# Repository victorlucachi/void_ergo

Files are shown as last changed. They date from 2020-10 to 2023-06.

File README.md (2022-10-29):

# VOID Ergo S
*A handwired split keyboard, running QMK firmware*

VOID Ergo S

|  |  |  |
|---|---|---|

###### More renders [here](https://imgur.com/a/ki1BZij)

The VOID Ergo S is a 3d printed, handwired, split keyboard with a layout similar to the Iris/Corne/Kyria, running QMK Firmware on Pro Micro controllers. Connection between the two halves of the keyboard is made with an aux cable via serial.

I suggest printing the case using a 0.4 mm nozzle, supports are not needed but recommended for the bottom cases as the ports will print with less imperfections.

The brass inserts can be fixed in the bottom case by heating them and applying pressure with a soldering iron set to about 200-220C.

*VOID Ergo S with V1 of the VOID Ergo under it*

VOID Ergo Fat

# Handwiring guide

I've also put together a pretty visual handwiring guide for the VOID9, that you can browse over [here](https://victorlucachi.ro/journal/void9-wiring-guide/).

|  	|  	|  	|
|---|---|---|

# Bill of Materials

* 46 diodes (tme.eu [link](https://www.tme.eu/ro/en/details/1n4148-dio/tht-universal-diodes/diotec-semiconductor/1n4148/)/aliexpress [link](https://www.aliexpress.com/item/32729204179.html))
* 44/46 cherry mx style switches
* 24 AWG (0.2 mm2) wire
* 2 x Pro Micro (aliexpress [link](https://www.aliexpress.com/item/32902569443.html))
* 2 x EC11 Rotary Encoder (optional/aliexpress [link](https://www.aliexpress.com/item/32872039030.html) mounted to the plate using [this adapter](https://www.thingiverse.com/thing:3770166))
* 10 x M2x12 allen head screws (aliexpress [link](https://www.aliexpress.com/item/32966941844.html), 14mm overall length, 4mm diameter head)
* 10 x M2 brass inserts (aliexpress [link](https://www.aliexpress.com/item/4000585933306.html), 3.5mm outer diameter)
* 2 x PJ320A 3.5mm female audio connectors (aliexpress [link](https://www.aliexpress.com/item/32368285821.html))
* 1 x 6x6x6 push button (optional (used to reset master)/aliexpress [link](https://www.aliexpress.com/item/32960657626.html))
* hot glue for securing the Pro Micros to the bottom case (optional, but recommended) the audio connectors and the reset push button.

# Pin assignment

    ROW0    ROW1    ROW2    ROW3
    B1      B3      B2      B6

    COL0    COL1    COL2    COL3    COL4    COL5
    D4      C6      D7      E6      B4      B5

    Encoder Pad A Left      Encoder Pad B Left
    F5                      F6

    Encoder Pad A Right     Encoder Pad B Right
    F6                      F5

    Serial Pin
    D1

*Matrix layout*

VOID Ergo S matrix layout

# QMK Vial Fork

A QMK Vial fork can be found [here](https://github.com/victorlucachi/vial-qmk/tree/dev_void/keyboards/handwired/void_ergo).

Most features are disabled in order for the firmware to fit on the atmega32u4 present on the Pro Micro controllers, but if you want to tinker around with different features or if you're using a different MCU you can enable/disable them to suit your own needs by editing the rules.mk file in the vial keymap folder.

The web version of Vial is available at [vial.rocks](https://vial.rocks/); it runs in supported browsers (Chrome, Edge and Opera) without requiring an installation.

VOID Ergo S Vial

# QMK Fork

A fork containing the QMK config files can be found [here](https://github.com/victorlucachi/qmk_firmware/tree/dev_void/keyboards/handwired/void_ergo). Edit them to suit your own needs and build the firmware following the QMK docs.

If you plan on using the VIA configurator dont forget to download the json definitions file linked in this repository.



This work is licensed under a [Creative Commons Attribution-NonCommercial-ShareAlike 4.0 International License](https://creativecommons.org/licenses/by-nc-sa/4.0/).

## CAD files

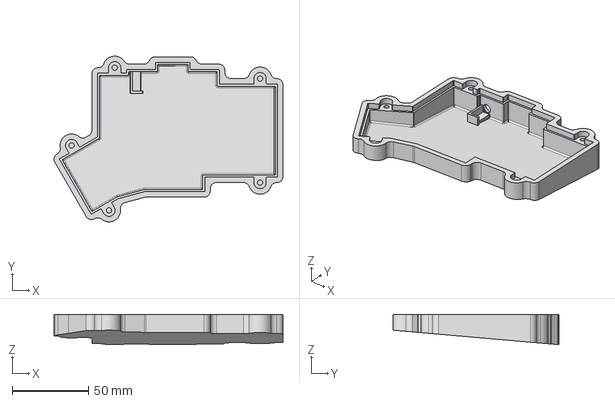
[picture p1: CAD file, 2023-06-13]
v1/STEP/VOID Ergo S - bottom_right.step
150.0 x 108.6 x 19.9 mm

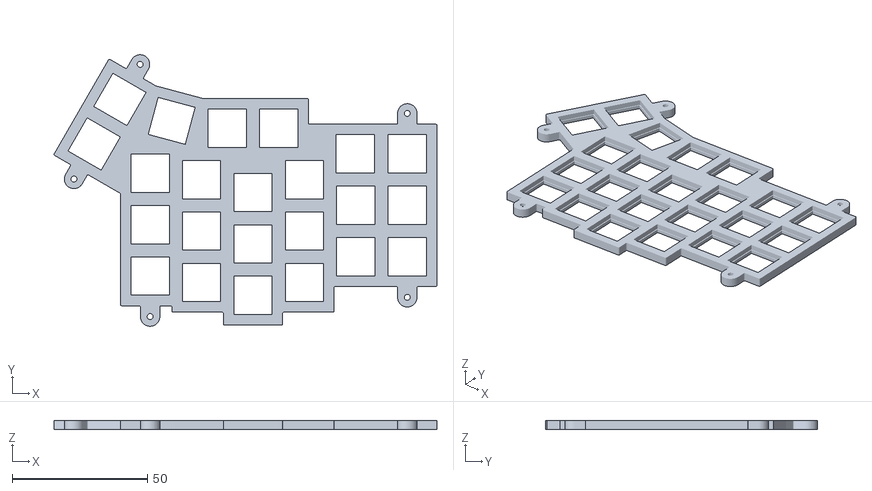
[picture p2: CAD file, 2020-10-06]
v1/STL/VOID Ergo S - plate_right.stl
141.8 x 100.6 x 3.40

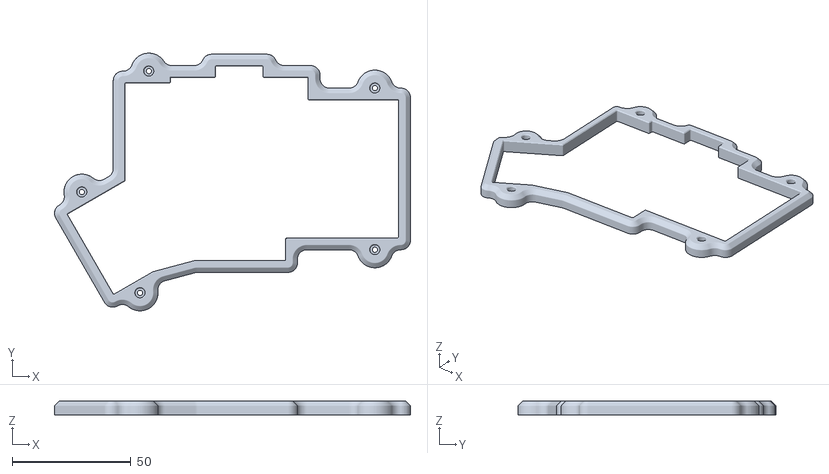
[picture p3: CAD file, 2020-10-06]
v1/STL/VOID Ergo S - top_right.stl
150.0 x 108.6 x 6.00

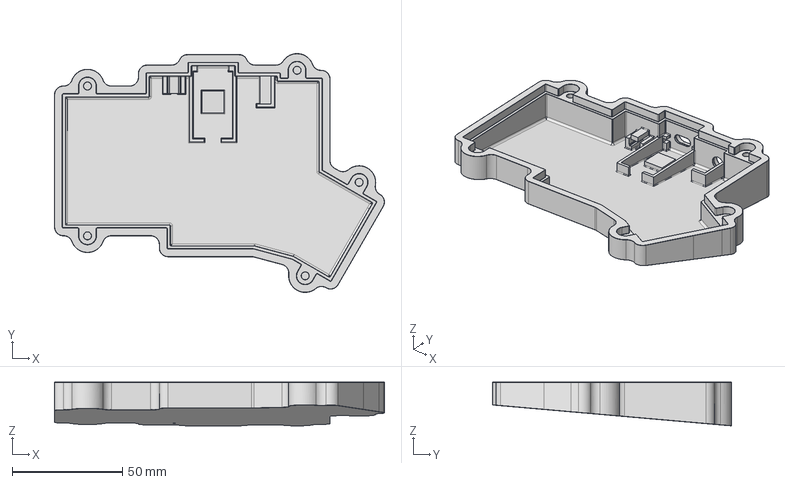
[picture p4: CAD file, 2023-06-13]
v1/STEP/VOID Ergo S - bottom_left.step
150.0 x 108.6 x 19.9 mm

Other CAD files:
v1/STEP/VOID Ergo S - plate_left.step
v1/STEP/VOID Ergo S - top_left.step
v1/STL/VOID Ergo S - bottom_right.stl
v1/STL/VOID Ergo S - plate_left.stl
v1/STL/VOID Ergo S - top_left.stl

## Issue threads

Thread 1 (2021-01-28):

Keycaps vs Layout

leo-vwdilab, 2021-01-28:
Sorry to open an issue but seemed like the quickest way to get in contact 😉

Interested in building one **void ergo** of my own and was wondering what keycaps did you use (or which ones can someone use) that would not impact with the layout?

Btw: Kudos for the design ⌨️🙏😉

victorlucachi, 2021-01-28:
Hey, and thanks! No worries, it is quite an effective way to get in touch after all, haha.

The plates are compatible only with Cherry MX style switches, so any compatible keycaps (that use the appropriate stems) should do the trick; all of the keys used in the layout are 1u. I personally used cherry profile, dsa and xda, and I did not encounter any issues.

Good luck with your build, and if you need any help dont hesitate to get in touch.

leo-vwdilab, 2021-01-28:
Many thanks, will keep you posted 😉

fairglen, 2021-03-04:
Hi @victorlucachi
Just dropping by to say thanks for sharing this project of yours 🥇 👍
This was the [result ](https://github.com/fairglen/qmk_firmware/tree/master/keyboards/handwired/void_ergo)

Do you have a paypal account or something, so that I can donate at least enough for a coffee?
Keep on 🤘

victorlucachi, 2021-03-05:
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

Hello!

Thank you for printing it, I love the end result! The orange filament is so vibrant! Hope you find it comfortable enough for daily use.
Personally I've been going back and forth between a Corne and my Ergo S, and I might be biased here, but I think I like the latter better.

Thanks again, and [a cup of coffee](https://paypal.me/victorlucachi) is much appreciated!

Closed 2021-01-28.

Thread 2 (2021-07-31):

Some questions about building Ergo S

Eloren1, 2021-07-31:
> 10 x M2 brass inserts (3.5mm outer diameter)

But what about length?

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

victorlucachi, 2021-07-31:
Hey, the ones I've used were 3mm. The insert holes themselves are about 6.7mm in depth though, so you could probably use longer inserts, but the max that I'd go with would be around 5mm, because some molten plastic will build up in the bottom of each insert.

Eloren1, 2021-08-04:
And another question, what's this?
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

Eloren1, 2021-08-04:
@victorlucachi can't reopen this issue btw

victorlucachi, 2021-08-04:
> And another question, what's this?
> 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

You probably missed it in the readme, it's a mounting slot for a 6x6x6 push button, used to reset the master side.

Eloren1, 2021-08-04:
Also I cannot find this layout in QMK Configurator. Nothing by searching `handwired/void_ergo`

victorlucachi, 2021-08-04:
> Also I cannot find this layout in QMK Configurator. Nothing by searching `handwired/void_ergo`

My builds are not added to the QMK repo, so no QMK Configurator support. You'd have to use my fork of QMK, which is also linked in the Readme, but it's not up to date and there have been some breaking changes ever since I last updated it; you'd probably have to fix any issues that may arise on your own, for the time being.

Eloren1, 2021-08-04:
Maybe I can use other QMK layouts like for Atreus 50

Eloren1, 2021-08-05:
@victorlucachi May I fork this project and add it to QMK Configurator? Your project will be linked in the readme. Keyboard name: Elrgo S. 😄

victorlucachi, 2021-08-05:
Reasoning behind this?

The keyboard wont get added to the QMK Configurator in a day or two, it takes months for a PR to get merged. You can fork and edit the files for the firmware as you see fit though.

I'm currently reworking the models for the entire keyboard range, after which I plan on going through the firmware and creating a PR for all of them myself.

Eloren1, 2021-08-05:
I just wanted to add configurator support. I will wait for your PR. But why do you want to rework models?

victorlucachi, 2021-08-05:
I want to make some small improvements to them, such as:

- moving on to smaller hardware on the other keyboards besides the Ergo, so M2 screws and heat inserts (with the current design the cases would get stress fractures after a while, depending on the screws used)

- moving the controller to be centered on the case and maybe a modular controller slot

- a better, recessed design for the USB port

- and a bunch of other stuff

victorlucachi, 2021-08-05:
As a sidenode, when I get to the firmware I plan on adding support for [Vial ](https://github.com/vial-kb) too. It's similar to VIA Configurator, but a bit cooler in my opinion.

Closed 2021-08-04.

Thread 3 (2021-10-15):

button port question

UwUham, 2021-10-15:
heyo, i was just wondering about this part in particular, cause i feel like it won't print well without supports. Am I supposed to try to insert the button mid print or something to help it stay up?

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

Thanks in advance!

UwUham, 2021-10-16:
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
do you think that this would be an adequate support beam for the part? sorry, i'm kind of a novice at 3D printing

victorlucachi, 2021-10-16:
No worries. I'm using Prusaslicer, it's my favorite slicer, and I'd set up something like this:

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

a scaled down support enforcer, that would cover the entire shape of the slot. when sliced, it would look like this:

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

patrickmcquay, 2021-10-19:
I just printed a set of these, they print surprisingly well, considering the small features. I too use prusaslicer, and the default supports work great.

Be careful getting that support material out though.

Closed 2023-06-13.

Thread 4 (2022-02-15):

Wiring the audio connectors

108085, 2022-02-15:
Hi there,
I'm currently getting all the parts together and I can't wrap head around how to wire the audio connectors to the pro micros.
I also only got 5pin audio connectors, but that shouldn't be a problem.
Is it just VCC, GND, TX and RX to the pins or the audio connectos and the same on the "slave" side, or do i have to do more/something else?

I would really appreciate a little push in the right direction.

Sorry for the maybe dumb question, but my only experience with hand wiring is the Void9 ;)

108085, 2022-02-15:
Nevermind... After days of search, I think i found the solution, minutes after posting the "issue"
https://gist.github.com/mtei/b1515eba3d20086da262c83948f8e9a9#soft-serial-connection
In your firmware you're just using D1 instead of D0.

Correct me if I'm wrong.

I leave that here, in case someone else has the same question.

victorlucachi, 2022-02-15:
Hey! Yes, that's it.

You can wire the audio connectors pins in whatever order you like, same mapping for the left/right half; gnd, vcc and d1, by default.

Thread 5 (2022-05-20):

Question about the material list info

renatosuero, 2022-05-20:
Hi @victorlucachi ,
first of all, thanks for sharing the amazing keyboard. I'll build that(I've already have the case, if you want some real photos I can send you).
I have some questions about the inserts and screws, can you help me, please?

We have a brass inserts in the list, but it doesn't mention the length, what do you suggest for that?
10 x M2 brass inserts (aliexpress [link](https://www.aliexpress.com/item/4000585933306.html), 3.5mm outer diameter
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
)

another one I'd like to confirm is that one
10 x M2x12 allen head screws (aliexpress [link](https://www.aliexpress.com/item/32966941844.html), 14mm overall length, 4mm diameter head)
I didn't get if I need the 12 or 14mm
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

renatosuero, 2022-05-20:
thank you very much. I'll order the missind components them I'll come back with case and keyboarb
btw the right side the bottom isn't equal the left one. I didn't realized when I've printed, for me it doesn't affect the usage so I'll go with that one
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

victorlucachi, 2022-05-20:
it's not equal in the sense that it's missing the controller mount and usb port? yes, that was intended, because I didnt want/need a port on my right hand. you can mirror the left half in your slicer of choice if you need easy access to the usb port though.

renatosuero, 2022-05-20:
yes it makes sense, there's no reason to reset or connect into the promicro. I'll build it soon and spam you with tons of photos  😂

renatosuero, 2023-04-14:
after long time, I'm back :joy: I'm finishing the keyboard, I'll be back with photos and try to help more in other issues

Closed 2023-06-13.

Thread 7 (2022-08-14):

Requesting additional Case & Switchplate model filetypes (namely .STEP for the dimensional data & encoding) for further-tuning the design for personal tastes.

PancakeGoon, 2022-08-14:
Hey there, @victorlucachi! MASSIVE fan of all of your boards - _especially_ the original  VOID Ergo & Ergo S!

&nbsp;&nbsp;&nbsp;&nbsp; First of all, I've sent you an e-mail correspondence through your site's contact form that goes into deeper detail for my plans, but figured I'd open this public official request to gauge other's possible interest in it as well.

But basically, I've wanted to build one of these for a while now & have also been learning Fusion360 for keyboard-related projects and designs. I'm also someone that always likes to customize or modify my builds beyond original intention, and this is even more relevant with the open-possibilities or a handwired build - so I wanted to try my hand at tweaking the design of the case halves & plates to alter it into a sort-of unofficial "Goon-efied" Ergo S fork as design-practice, whilst keeping the nod to the original and also releasing the files myself. Also gives the masses the same customization freedom!

The only issue I've had so far _(which is quite early-on, I admit... 🙃)_, __is the fact that .STL files are a _MISERY_ to edit or modify—in any serious way—in a 3D-modelling/CAD context...__
&nbsp;&nbsp;&nbsp;&nbsp; &nbsp;&nbsp;&nbsp;&nbsp; No in-coded Dimensions/tolerance data—this is especially a pain with Fusion 360, when it ACTUALLY wants to import external files like DXF's or STL's correctly... it's still an issue for _confirmed-working_ models/vectors to import with bugged-out scaling, and good luck trying to edit that further as STL—they can't encode real curves, it's just surface data, etc. - which is fine for 3DPrinting, which is also the intent here, I get that! And .DXF's are fine for the plates.

\- But including .STEP (or even better' **Fusion's .f3d project files**, if you used the program =D - although I totally understand if you'd like to keep that depth of your IP to yourself!) would make this board a fantastic resource as a split case-design reference, as well as enabling the ability for fans like myself to further tune & perfect the design to our personal tastes and physical differences.

Thanks, dude!

victorlucachi, 2022-08-17:
hey there PancakeGoon,

sorry for the late reply, to begin with; the email contact form, and the website for that matter, are in total shambles. opening this issue was probably the best course of action.

thank you for the kind words, much appreciated! I can totally relate to your situation, the driving force behind these projects, among other things, was to learn some cad design.

I would usually suggest starting from scratch, as in my opinion it's always best to start with a clean slate instead of tweaking or figuring out someone else's mess, but I dont mind posting the .step files, if you do choose to alter the plates or the case.

[I'll attach them here](https://github.com/victorlucachi/void_ergo/files/9358002/VOID.Ergo.S.-.step.zip) (bottom, top and plate for the left half, only bottom for the right half, because the other parts can be mirrored), and add them to the repository later.

thanks for getting in touch, and It would also be awesome if you'd post the remixed files somewhere, maybe for other people to use if they find them of interest.

PancakeGoon, 2022-08-18:
@victorlucachi
Oh man, you are just the best for this! Thank you so much for the speedy response, too. 👍
And lol, I'll keep that in-mind about your site and contact from here on out, and you can be __sure__ I'll be uploading everything I come up with dude! I still have a couple other project cases and stuff in-line, but I'll definitely be sticking my nose in & out of this in the mean-time. :D

Closed 2022-08-17.

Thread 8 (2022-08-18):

Question about licence

EdwardNavarro, 2022-08-18:
Hi @victorlucachi ,

First, congratulate you for amazing job with void_ergo 💯 .

I'm interested in design a PCB compatible with your case because actually I prefer PCB over handwired keyboards.

So, my question is how the license you have for this project works for my case. I want make it public in the future for everyone without any restrictions, but first, I want to know and be sure about all legal matters. I don't know how the license works.

Thanks so much for you time and help.

victorlucachi, 2022-08-18:
Hey @EdwardNavarro!

Thank you, appreciate the kind words.

As far as a PCB for the Ergo goes, from my point of view, there are a couple limitations from the start:
- limited space between pcb edge cut and case itself; hotswap sockets are probably not an option with the current case dimensions
- port (usb/trrs jack) placement will definitely have to get tweaked.

The license; you could basically design and sell a PCB of your own for profit, if you choose to do so, or make the project available for free (you could also use a license that allows people to use, share, adapt your design, but not use it commercially).

Keeping in mind the issues mentioned above regarding the 3d models, you would also have to remix the case based on the available STEP files from this repository; you would have to share the remixed case for free, state any changes that you made to it, and you wouldnt be able to sell prints of it or full builds, for profit.

I'd love to see some of your previous PCB designs; I've tried my hand at it for one of my macropads, a couple of revisions for it, but I'd like to learn more about it.

Thank you!

Closed 2023-06-13.

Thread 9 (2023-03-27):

About wiring guide

jmvega-pki, 2023-03-27:
The little wiring guide ins awesome BUT, could please upload the pinout of the micros for this project? I'm a little lost.
Also will be an extra the use you give to knobs and how to configure them.

Of course, if this can be solved with just a link... job done!
Thanks!!

daithanhtran2912, 2023-03-31:
Hi Victor! I'm not sure it is ok if I should create a new issue to ask about my questions so I'm gonna post it here:
- For the TRRS jack `serial wiring`:  I'm curious about what method should I go with `(Bitbang/Half-duplex/Full-duplex)`? To my understanding from QMK docs and your firmware, I should go with `Bitbang` method, but how about the `Half-duplex` and `Full-duplex` methods?
- Is that possible if I want to use the `Full-duplex` method, and what should I do with the firmware? Do I have to modify it?

Thank you!!!

victorlucachi, 2023-03-31:
hey @daithanhtran2912

if you're using pro micros or any atmega32u4 based controllers you're pretty much stuck with bitbanging. half/full duplex usart is compatible only with arm controllers.

all the methods that you mentioned, as well as instructions to enable each of them, are documented [here](https://github.com/qmk/qmk_firmware/blob/master/docs/serial_driver.md).

I've personally used only avr controllers with qmk split keyboards, I cant say if there is any real benefit in using one method over the others, but if you plan on building an Ergo with arm based controllers you will definitely have to configure the firmware from scratch.

daithanhtran2912, 2023-03-31:
Hi @victorlucachi, thank you for your fast response.
Currently, I'm using `Pro micro` for my Ergo. As you mentioned above, pretty sure that I only have two options `bitbanging` and `I2C wiring`.
Now I'm curious about the `I2C wiring`. Is that possible to use it for this project?

daithanhtran2912, 2023-04-01:
Hi @victorlucachi!

Thank you for the information and sorry if I make everything complicated. I'm not a fast typer. My typing speed is around 80-100 wpm. And yes, the latency is what I'm wondering about. Does the latency of the bit bang serial is something noticeable?

I'm also open to experimenting with something new. So if i2c could make the latency better, I think I'm gonna go with it XD.

Finally, thank you for creating and making this keyboard available for everyone, it is a piece of art!!!

(I want to share my W.I.P Ergo but don't know where to post it. I haven't attached the top and the bottom case together)
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

victorlucachi, 2023-04-01:
it's all good @daithanhtran2912 and I was just curious, haha. there's nothing wrong with wanting to use i2c, and to be honest I only went with serial because it was the default option and it seemed to work for everyone else.

I for one cant notice any input lag with bit bang serial, I've used it with the Ergo and with my Corne builds, but these days I've moved on to zmk and ble wireless controllers (and I still cant notice any lag whatsoever, even though on paper it should technically be slower? I can still type at an average of 100 wpm).

I did a quick search and discovered some rather old talk on the qmk discord server, mentioning tests and changes [for the Let's Split keyboard](https://github.com/qmk/qmk_firmware/pull/7732) and the conclusion was in fact that out of the box serial is faster than i2c. there's probably more info regarding this on the server as well, but I'm not smart enough to dive into the intricacies of qmk configuring though.

if you want to switch to i2c you will have to wire the d0/SCL pin on the controllers to the trrs jacks and add the pullup resistors, comment out or remove [the following line](https://github.com/victorlucachi/qmk_firmware/blob/dev_void/keyboards/handwired/void_ergo/info.json#L21) and add `#define USE_I2C` to the `config.h` file. [this should cover it](https://github.com/qmk/qmk_firmware/blob/master/docs/feature_split_keyboard.md#i2c-wiring), in case that I missed anything else.

thank you for the kind words, I appreciate it!

that's a really clean build, you really went the extra mile, that paintjob is impeccable! if you didn't wire it up already I suggest using magnet (or enameled) wire, as it is thinner than normal wire, and it should help a bit in regards with the limited space inside the case. I'm looking forward to seeing your completed project and your impressions on it!

the reddit ergomechboards/handwiredkeyboards, or the multiple mechanical keyboard discord communities would probably be great places to share it with other people too!

daithanhtran2912, 2023-04-01:
Hi @victorlucachi, thank you for your detailed instructions!

Yeah, I haven't wire it up and I planning on using enameled wire as well (I just want to go a little bit crazy over here XD).

I will share the project on reddit when I'm finished.

Thank you so much for helping me!

renatosuero, 2023-04-14:
yesterday I finished all soldeding, (except the encoder yet) today I want to test all switches, once everything is good I'll return with encoders.

Closed 2023-06-13.

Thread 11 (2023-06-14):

TRRS Pins Clarification

codercodingthecode, 2023-06-14:
Needing some clarification with TRRS wires.

The Void Ergo uses
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

The TRRS pinout uses a different approach to share power with the slave board.

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

I understand we are using SDA D2 pin and D20/D19 for Void Ergo
On the TRRS pinout is different using GND and VCC

Do we need 5 wires[D2, GND, VCC, D19,D20] or 3 wires?[D2, GND, VCC ] ?

Can someone clarify the proper connection with the TRRS wires?

victorlucachi, 2023-06-14:
hey @codercodingthecode!

as outlined [here](https://github.com/qmk/qmk_firmware/blob/master/docs/feature_split_keyboard.md#serial-wiring), and on the diagrams that you posted above, the serial connection between the central and peripheral half uses only 3 pins: VCC, GND and either PD0/PD1/PD2/PD3.

in our case, for the void ergo, the predefined config uses the PD2 pin, so you would need to wire up the trrs jacks with VCC, GND, PD2. as for PD19 and PD20, they have nothing to do with serial, and they're used for the encoders.

hope this clears things out

codercodingthecode, 2023-06-16:
Thanks @victorlucachi .
One more question regarding pinouts.

Keyboard vs pro micro

Left side [master]
The software will be compiled separated for left and right with handedness by eeprom
https://docs.qmk.fm/#/feature_split_keyboard?id=handedness-by-eeprom

Does this wiring seem accurate?

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

victorlucachi, 2023-06-16:
the 3d models assume that left half is central, I never messed with eeprom handedness, by default my fork uses [split_usb_detect](https://github.com/qmk/qmk_firmware/blob/master/docs/feature_split_keyboard.md#hardware-configuration-options). same firmware for both halves.

diode direction is col2row.

the rows are correct, as per your diagram, but the columns are not. you will want to wire up your right half like so:

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

codercodingthecode, 2023-06-16:
Thanks for the clarification.
Based on what I’ve seen around when researching hand wired keyboards. It seems to be a common question for starters.

This is my first keyboard build. I’ve should’ve started with a no split I guess 😄

Anyhow, I still can’t get the right hand split to work probably.
I’ve wired the right half as described above. And I still get the keys all messed up. The left side is good though.
I’ve checked for shorts on both ends and everything seems good. 🤷‍♂️

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

codercodingthecode, 2023-06-17:
Actually, I had unsoldered and soldered the same way back up lol
I fixed it and now it works.

Thank you for the help and for the project!

victorlucachi, 2023-06-17:
awesome, glad to hear that it's working!

I've been handwiring boards for a couple of years now, and I still make these kind of mistakes, I guess it comes with the territory.

anytime, thank you for printing and building it, hope you'll find it enjoyable to use!

Closed 2023-06-17.

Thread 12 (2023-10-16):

Switch Plate holes are a tad too big

Aggeloz, 2023-10-16:
Im using a Prusa Mk3s+ with the prusa slicer and i discovered that the switch holes are a tad too big and the switches move way too much and dont hold on too well. What could i do to fix this issue?

victorlucachi, 2023-10-17:
the models switch holes measure 14.2 mm (.2mm extra for tolerance, because not all printers are equally calibrated). if you have some calipers on hand you could measure the holes, determine their dimensional accuracy, and adjust the .step file accordingly. another option would be to hotglue the switches in place.

R3ISilva, 2024-04-17:
I also have find these to be true on the plate left stl file, just fliped the plate right and reprinted it for thight fit.

Closed 2023-10-17.

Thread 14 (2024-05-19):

Single switch PCB

faboulaws, 2024-05-19:
Hi,

I wish to build this keyboard while supporting hot-swap. Is there enough space to support single  switch PCBs?

Thanks. :-)

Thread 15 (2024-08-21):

Advice on making a modified version as a first split ergo keyboard

clorl, 2024-08-21:
Hello, this repo hasn't a lot of activity so I hope this message gets to someone.

I'm looking to upgrade my cheap 20$ keyboard to a split mech but I'm on a budget. I thought about hand wiring it myself and found your design.

However, it doesn't quite fit my needs, the modifications I'd need would be :
- Low profile Choc switches
- 58 keys (similar to the Sofle)

I have experience in electronics/CAD/3D printing and programming. I already assembled an open source hardware project (a [PhobGCC controller](https://github.com/PhobGCC/PhobGCC-HW)). I have lots of tools and basic electronic parts at home, a 3D printer and a local maker's lab, bit no switches or keycaps on hand.

How hard can it be to modify your design to fit my needs given my level of experience? Do you have directions or general advice on how to do this?

Thanks for the advice

victorlucachi, 2024-08-21:
hey clorl,

you seem pretty skilled. considering your needs, if you're good with CAD it might make more sense to start from scratch, and take design cues from my models, if it's something that you find appealing. in my opinion adapting the existing files to accommodate a larger number of keys would only add more headaches than necessary, because it will require lots of adjustments.

[ergogen](https://github.com/ergogen/ergogen) could make things quite easy, regardless if handwiring or choosing to use a pcb, for the initial layout of the keys and even for designing a case. I highly suggest looking into it.

clorl, 2024-08-21:
Thanks for the advice, however the point I'm not sure about is on what to put the switches if there's no PCB? I guess I should print some kind of plate for the keys to go on in place of a PCB right?

I'll look into more documentation on the subject, thanks for the reply

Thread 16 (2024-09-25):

Adding hotswap sockets

andrwui, 2024-09-25:
Hi!

Would it be possible to add hotswap sockets to the build?
I'm asking because I like to change switches every now and then, and as the build isn't planed with hotswap sockets in mind, they may not fit in the casing.

Thank you for the amazing design!

victorlucachi, 2024-09-26:
hey, thank you for the kind words.

you could adapt the switch plates to fit hotswap sockets, but it might be just a little bit too tight; there's almost no room to spare towards the front of the case, under the thumb cluster, and above the controller as well.

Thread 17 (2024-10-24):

i think i did something wrong

andrwui, 2024-10-24:
I started assembling the keyboard today, I already assembled the right half, the left one is still not finished.

I to plugged the assembled half of the keyboard to the computer, and entered vial, to test everything was ok.

The keyboard worked, but it showed the left keyboard being pressed, which i thought it was normal because the firmware uses split detection, but also the keys were mirrored, so if i pressed the most upright left key, it will show the most upright right key.

I think i messed up soldering the diodes:

For the right half, the diodes are facing < and for the left half diodes are facing > (they are mirrored, facing to center)

Are the keys being mirrored because of this? Or is it that i haven't plugged both halves?

If I did mess up, is there a way through firmware I can tell qmk that diodes are the wrong way? I know I can just mirror the layout in vial,
but I just wanted to know if there is a fix firmware-wise.

Also, desoldering is not an option i think.

Thanks for the awesome keyboard!!!

victorlucachi, 2024-10-24:
Pictures of the diodes/soldering would help paint a better picture, but as far as I can tell from what you're describing, it shouldn't be an issue (diodes can be installed either row2col or col2row, and you can set their direction in firmware, but they have to be soldered the same way across both halves).

Are you sure that your column wiring to the controller is not mirrored on the right half? I've seen that happen before.

andrwui, 2024-10-24:
Diodes for the right half are soldered this way:

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

And the diodes for the left half are soldered this way:

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

The columns are wired to the controller from left to right on both halves, I think I got that right.

Thank you for the answer!

victorlucachi, 2024-10-24:
Diodes seem fine, it doesn't matter which way their ends are pointing, electrically speaking the circuit is the same. But yeah, as long as your controller wiring checks out, everything should be good (you could take a look at [this](https://github.com/victorlucachi/void_ergo/issues/11#issuecomment-1594200109) wiring diagram for the column order and compare it with yours).

andrwui, 2024-10-25:
I was indeed mirroring the columns on the slave...

Now i'm having another problem...

I got them both to correctly work separately. But when i connect the trrs cable to connect them, the slave does not work, i see it's getting powered, but keystrokes do nothing.

The master works just fine, but the slave does not.

I thought it would be a problem with the trrs port wiring, but I don't think it's the case.

For context, here's pictures of the wiring:

Master:
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

Slave:
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

victorlucachi, 2024-10-26:
disabling the encoders in config and building the firmware from my fork, or just flashing the precompiled vial hex that's uploaded to this repo? please try the latter too, if you haven't already.

FedeArre, 2024-10-27:
> disabling the encoders in config and building the firmware from my fork, or just flashing the precompiled vial hex that's uploaded to this repo? please try the latter too, if you haven't already.

@andrwui forgot to post the fix, the issue was with the 3.5mm connection not fully inserting because of the 90° input. Trimming a bit of the protective rubber allowed it to fit perfectly, and the slave started working without issues."

victorlucachi, 2024-10-27:
that's great news, I'm glad it's working

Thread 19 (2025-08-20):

Keyboard not detected on startup unless USB C cable is replugged

PatrickEvan071, 2025-08-20:
When I leave my Void Ergo keyboard (Pro Micro) plugged in overnight while my computer is off, the keyboard appears to power on after the computer starts, but it does not register any input. To get it working, I have to unplug and replug the USB-C cable. I’m using the provided vial-qmk firmware from this repository, so I’m not sure if the issue is firmware-related. I’ve seen a few people on Reddit mention similar issues, with the suggested fix being to add: #define WAIT_FOR_USB

I attempted to compile my own firmware from the vial-qmk fork with this change, but I wasn’t able to successfully do so as I’m still inexperienced with QMK.

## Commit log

2020-10-06 updated models with correct orientation
    [VOID Ergo S - bottom_right.stl, VOID Ergo S - plate_left.stl, VOID Ergo S - plate_right.stl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]
2022-08-17 added step files
    [VOID Ergo S - bottom_left.step, VOID Ergo S - bottom_right.step, VOID Ergo S - plate_left.step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]
2023-06-13 redux prep
    - restructured repo
    - added precompiled fw
    - prep for redux models
    [VOID Ergo S - bottom_left.step, VOID Ergo S - bottom_right.step, VOID Ergo S - bottom_right.stl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]

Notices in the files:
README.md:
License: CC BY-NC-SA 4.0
